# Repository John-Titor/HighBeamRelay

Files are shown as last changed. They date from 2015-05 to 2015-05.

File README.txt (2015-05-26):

High-beam switching relay, suitable for low/high 
beam switching with aftermarket Bi-Xenon headlights 
in older VW/Porsche applications.

The unit should be powered from the low-beam light 
power, and the IN pin pulled to ground by the high-beam
switch. The OUT pin should be connected to the positive
terminal of the Bi-Xenon high-beam solenoids.

If the IN pin is pulled briefly to ground, a 250ms flash
followed by a 250ms off period will be generated. If the
pin is held to ground for more than 350ms, the relay will
latch on and remain on until the IN pin is disconnected
from ground and then reconnected.

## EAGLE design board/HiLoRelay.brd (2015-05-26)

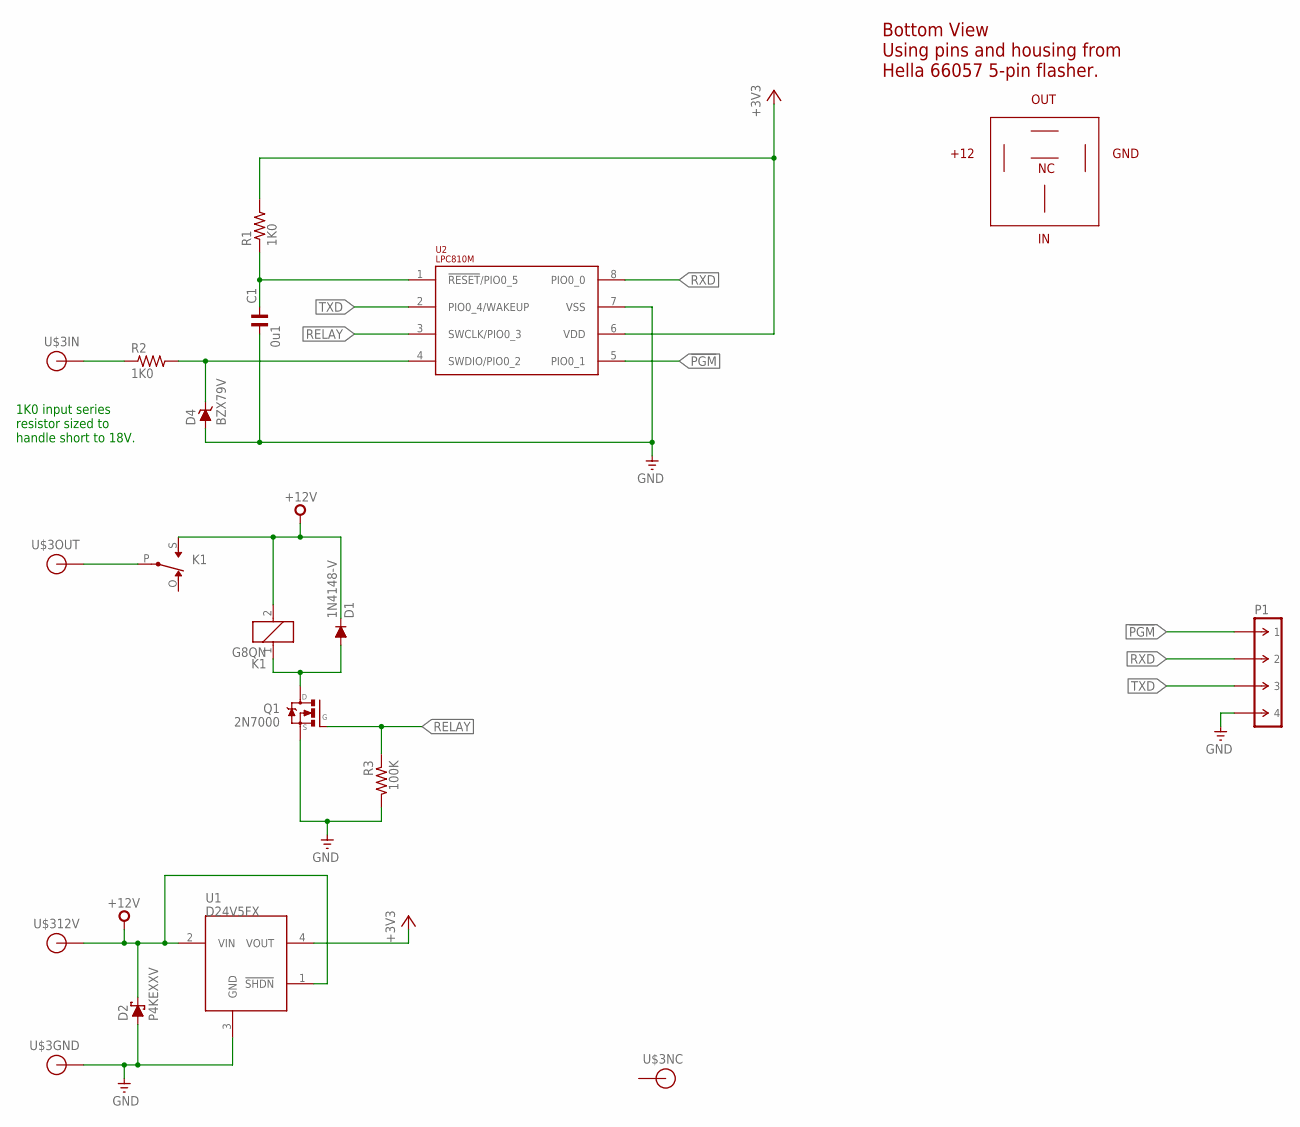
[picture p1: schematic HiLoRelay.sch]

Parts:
C1: 0u1; C025-024X044; PARTNO FK18X7R1E104K
D1: 1N4148-V; DO35-V; PARTNO 1N4148
D2: P4KEXXV; DO41-V; PARTNO P4KE30CA
D4: BZX79V; DO35-V; PARTNO TZX3V3A-TR
K1: G8QN; PARTNO G8QN-1C4-DC12
P1: M-1X04-SIP-100-32; SIP-100-04-32; PARTNO 961104-6404-AR
Q1: 2N7000; TO-92; PARTNO 2N7000
R1, R2: 1K0; 0207/2V; PARTNO MFR-25FBF52-1K
R3: 100K; 0207/2V; PARTNO MFR-25FRF52-100K
U1: D24V5FX; SIP-100-04-32
U2: LPC810M; DIL08; PARTNO LPC810M021FN8FP
U$3: TRIDON_PIN_BASE

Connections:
!PGM: P1.1, U2.5 (PIO0_1)
+3V3: R1.2, U1.4 (VOUT), U2.6 (VDD)
+12V: D1.C, D2.C, K1.2, K1.S (NO), U1.1 (!SHDN), U1.2 (VIN), U$3.12V
GND: C1.2, D2.A, D4.A, P1.4, Q1.1 (S), R3.2, U1.3 (GND), U2.7 (VSS), U$3.GND
unnamed: D1.A, K1.1, Q1.3 (D)
unnamed: R2.1, U$3.IN
unnamed: D4.C, R2.2, U2.4 (SWDIO/PIO0_2)
unnamed: C1.1, R1.1, U2.1 (!RESET!/PIO0_5)
OUT: K1.P (COM), U$3.OUT
RELAY: Q1.2 (G), R3.1, U2.3 (SWCLK/PIO0_3)
RXD: P1.2, U2.8 (PIO0_0)
TXD: P1.3, U2.2 (PIO0_4/WAKEUP)

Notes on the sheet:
+12
GND
OUT
Bottom View Using pins and housing from Hella 66057 5-pin flasher.
1K0 input series resistor sized to handle short to 18V.

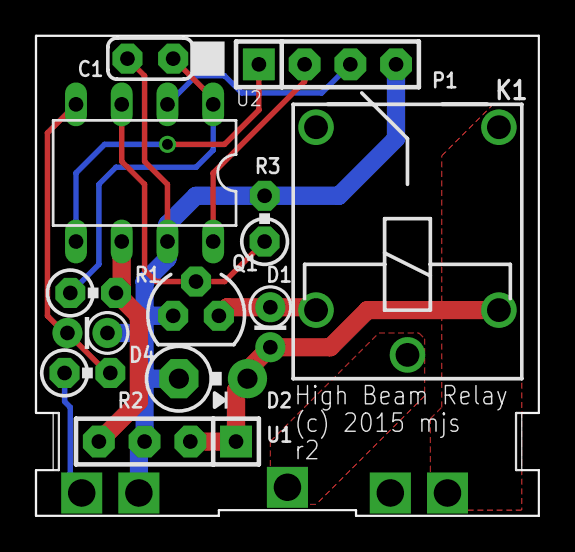
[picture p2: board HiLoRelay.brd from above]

Board: 2 copper layers, 27.9 x 26.7 mm, 13 parts (0 on the bottom side), 12 nets.

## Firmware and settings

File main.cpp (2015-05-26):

// Copyright (c) 2015 Michael Smith, All Rights Reserved
//
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
//  o Redistributions of source code must retain the above copyright
//    notice, this list of conditions and the following disclaimer.
//  o Redistributions in binary form must reproduce the above copyright
//    notice, this list of conditions and the following disclaimer in
//    the documentation and/or other materials provided with the distribution.
//
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

#include <sysctl.h>
#include <pin.h>
#include <timer.h>
#include <uart.h>
#include <interrupt.h>

#define SWITCH      P0_2
#define RELAY       P0_3

#define flashTimer  Timer0
#define switchTimer Timer1

#define DEBUG(str)  do { UART0 << str << "\r\n"; } while(0)

static const unsigned   kDebounceTime = 10 * 24000;
static const unsigned   kMinOnTime = 200 * 24000;
static const unsigned   kMinOffTime = 200 * 24000;
static const unsigned   kSwitchTime = 350 * 24000;

extern "C" int main();

int
main()
{
    enum {
        WAITING_OFF,
        FLASH_DEBOUNCE,
        FLASHING,
        FLASH_HOLD,
        FLASH_WAIT,
        LATCHED_ON,
        CANCEL_DEBOUNCE,
        CANCELLING
    } state = WAITING_OFF;

    Sysctl::init_24MHz();

    // UART output for debugging
    UART0_TXD.claim_pin(P0_4);
    UART0.configure(57600);
    DEBUG("START");

    // relay output configured and driven low
    RELAY.configure(Pin::Output, Pin::PushPull);
    RELAY << 0;

    // switch input configured and waiting to be pulled low
    SWITCH.configure(Pin::Input, Pin::PullUp | Pin::Invert);

    // spin forever
    for (;;) {
        //Interrupt::wait();

        switch (state) {
        case WAITING_OFF:

            // reset all our state
            RELAY << 0;
            switchTimer.cancel();
            flashTimer.cancel();

            if (SWITCH) {                           // switch closed, start debouncing
                switchTimer.configure(kDebounceTime);
                state = FLASH_DEBOUNCE;
                DEBUG("FLASH_DEBOUNCE");
            }
            break;

        case FLASH_DEBOUNCE:
            if (!SWITCH) {                          // switch opened before debounce period expired
                state = WAITING_OFF;
                DEBUG("WAITING_OFF1");
            } else if (switchTimer.expired()) {     // debounce period expired, switch is really closed
                state = FLASHING;
                RELAY << 1;
                switchTimer.configure(kSwitchTime);
                flashTimer.configure(kMinOnTime);
                DEBUG("FLASHING");
            }
            break;

        case FLASHING:
            if (!SWITCH) {                          // switch has opened
                if (switchTimer.expired()) {        // latch-on timer has expired, stay on until cancelled
                    state = LATCHED_ON;
                    DEBUG("LATCHED_ON1");
                } else {
                    state = FLASH_HOLD;
                    DEBUG("FLASH_HOLD");
                }
            }
            break;

        case FLASH_HOLD:
            if (flashTimer.expired()) {             // wait until the minimum flash time has passed
                RELAY << 0;
                flashTimer.configure(kMinOffTime);
                state = FLASH_WAIT;
                DEBUG("FLASH_WAIT");
            }
            break;

        case FLASH_WAIT:
            if (flashTimer.expired()) {
                state = WAITING_OFF;
                DEBUG("WAITING_OFF2");
            }
            break;

        case LATCHED_ON:
            if (SWITCH) {                           // switch closed, start debouncing
                switchTimer.configure(kDebounceTime);
                state = CANCEL_DEBOUNCE;
                DEBUG("CANCEL_DEBOUNCE");
            }
            break;

        case CANCEL_DEBOUNCE:
            if (!SWITCH) {                          // switch opened before debounce period expired
                state = LATCHED_ON;
                DEBUG("LATCHED_ON2");
            } else if (switchTimer.expired()) {
                state = CANCELLING;
                DEBUG("CANCELLING");
            }
            break;

        case CANCELLING:
            if (!SWITCH) {
                state = WAITING_OFF;
                DEBUG("WAITING_OFF3");
            }
            break;

        default:
            switchTimer.cancel();
            state = WAITING_OFF;
            DEBUG("WAITING_OFF ERROR");
        };
    }
}

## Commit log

2015-05-26 Initial checkin of the High/Low beam relay design
    [HiLoRelay.brd, HiLoRelay.sch]
2015-05-26 Wire up the classlib as a submodule

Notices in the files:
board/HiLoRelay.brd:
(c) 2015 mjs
